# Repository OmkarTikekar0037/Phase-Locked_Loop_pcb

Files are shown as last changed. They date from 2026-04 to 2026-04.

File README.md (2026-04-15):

# Discrete Phase-Locked Loop (PLL) on PCB

This project implements a **fully discrete Phase-Locked Loop (PLL)** using standard logic ICs, analog components, and a voltage-controlled oscillator on a custom PCB. The goal is to bridge theoretical understanding of PLLs with practical hardware realization by designing, building, and analyzing a complete feedback synchronization system.

---

## 🔷 Overview

The PLL is designed to:

* Lock onto an external reference signal (100 Hz – 10 kHz range)
* Perform **frequency multiplication** (×2, ×4, ×8 configurable)
* Demonstrate **lock acquisition (capture)** and **tracking (lock range)** behavior
* Provide observable internal signals for analysis (UP, DOWN, Vctrl, VCO output)

This implementation emphasizes **control system behavior**, **nonlinear dynamics**, and **real-world circuit constraints**.

---

## 🔷 System Architecture

The PLL is composed of the following functional blocks:

1. **Phase Frequency Detector (PFD)**

   * Built using dual D flip-flops and NAND logic
   * Generates UP/DOWN signals based on phase and frequency difference

2. **Charge Pump**

   * Converts digital UP/DOWN pulses into current pulses
   * Controls charging/discharging of the loop filter

3. **Loop Filter (RC Network)**

   * Integrates charge pump output into a smooth control voltage (Vctrl)
   * Defines loop dynamics (bandwidth, damping, stability)

4. **Voltage Controlled Oscillator (VCO)**

   * Implemented using a 555 timer in voltage-controlled mode
   * Output frequency varies with Vctrl

5. **Frequency Divider**

   * Digital counter used to scale down VCO output
   * Enables frequency multiplication in closed loop

---

## 🔷 Key Design Features

* **Second-order PLL design** with tunable damping factor (ζ ≈ 0.7)
* Adjustable loop parameters (R, C, charge pump current)
* Modular block-based design for easy debugging and testing
* Dedicated test points for internal signal observation
* Separation of analog and digital sections for noise reduction

---

## 🔷 Learning Objectives

This project demonstrates:

* Practical implementation of **feedback control systems**

* Relationship between **phase, frequency, and time-domain behavior**

* Design trade-offs between:

  * Stability vs speed
  * Capture range vs noise
  * Loop gain vs oscillation

* Real-world non-idealities:

  * Charge pump mismatch
  * Loop filter noise sensitivity
  * VCO nonlinearity

---

## 🔷 Observations & Experiments

The setup allows direct observation of:

* Lock acquisition process (capture range behavior)
* Stable locked state (minimal phase error)
* Effect of loop filter parameters on system response
* Impact of VCO gain and charge pump current on stability

---

## 🔷 Applications

While implemented as a low-frequency prototype, the same principles apply to:

* Microcontroller clock generation
* RF frequency synthesizers
* Motor synchronization systems
* Communication systems (clock/data recovery)

---

## 🔷 Project Significance

This project serves as a **hardware-level exploration of PLLs**, transforming abstract concepts into measurable electrical behavior. It provides a strong foundation for advanced topics such as:

* High-frequency PLL design
* Digital PLLs (FPGA-based)
* Control system modeling and stability analysis

---

## 🔷 Status

🚧 In development — includes schematic design, PCB layout, and experimental validation.

---

## 🔷 Author

Omkar Tikekar
Electronics & Telecommunication Engineering

---

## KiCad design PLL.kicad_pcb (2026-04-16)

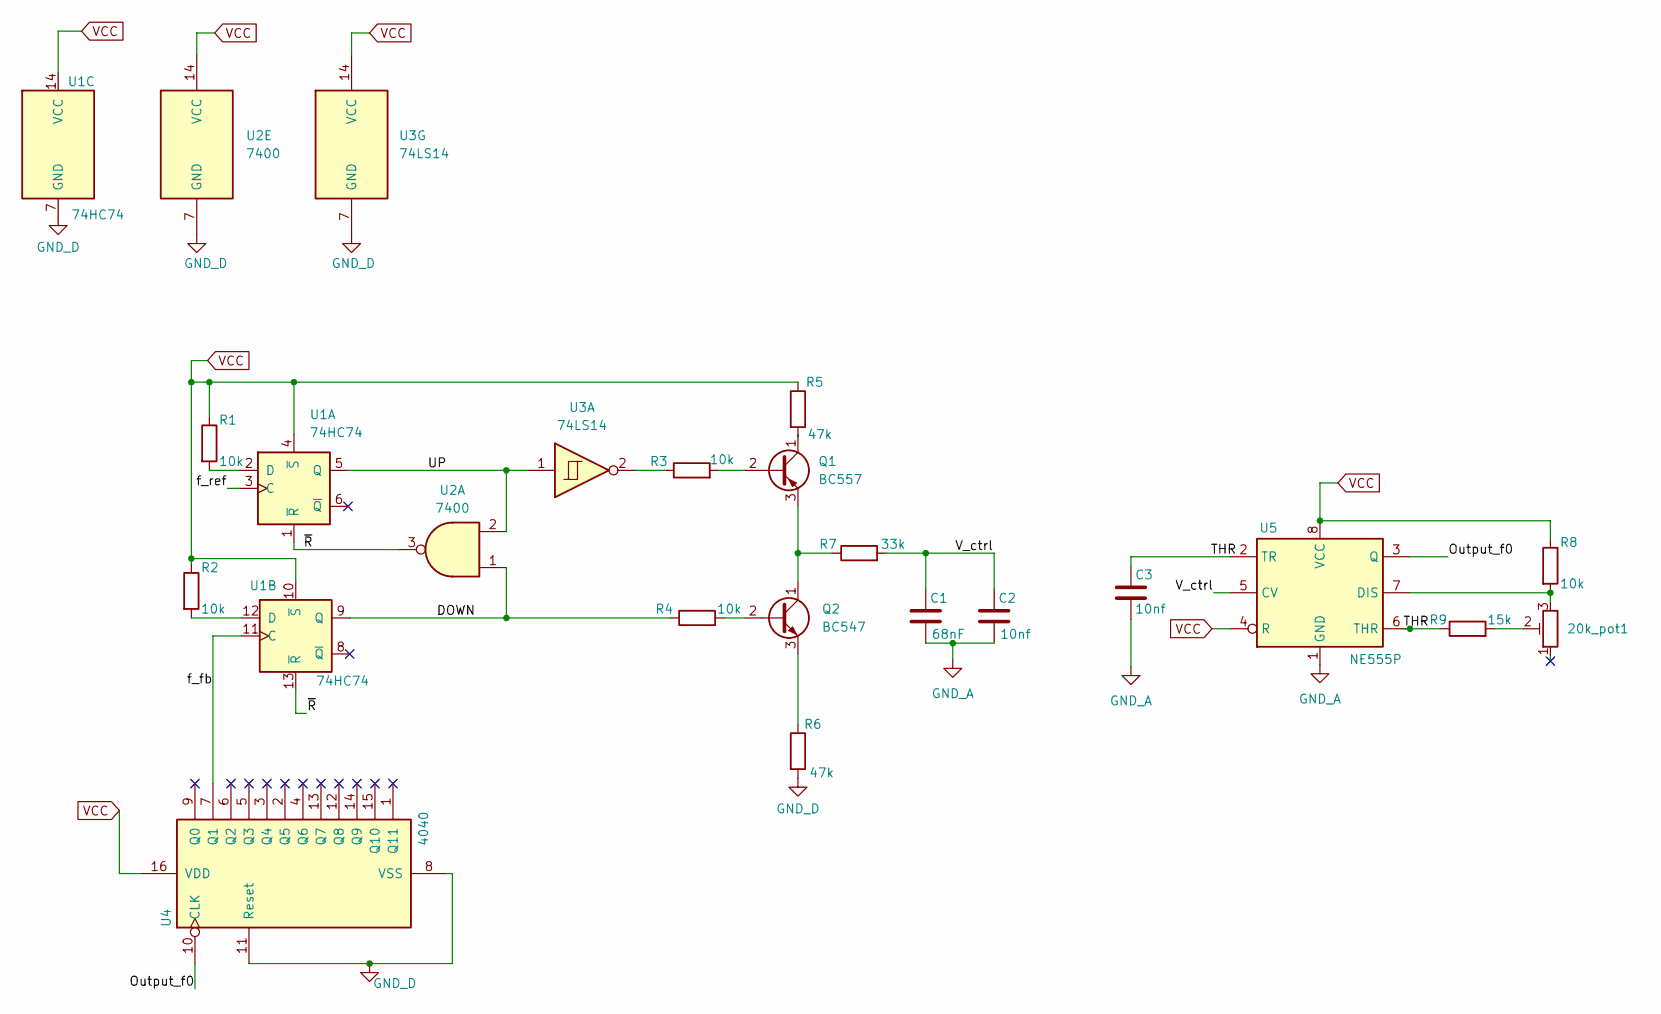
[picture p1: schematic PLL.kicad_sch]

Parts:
20k_pot1: R_Potentiometer_Trim; Potentiometer_Runtron_RM-063_Horizontal
C1: 68nF; C_Disc_D3.0mm_W1.6mm_P2.50mm
C2, C3: 10nf; C_Disc_D3.0mm_W1.6mm_P2.50mm
Q1: BC557; TO-92_Inline
Q2: BC547; TO-92_Inline
R1, R2, R3, R4, R8: 10k; R_Axial_DIN0207_L6.3mm_D2.5mm_P7.62mm_Horizontal
R5, R6: 47k; R_Axial_DIN0207_L6.3mm_D2.5mm_P7.62mm_Horizontal
R7: 33k; R_Axial_DIN0207_L6.3mm_D2.5mm_P7.62mm_Horizontal
R9: 15k; R_Axial_DIN0207_L6.3mm_D2.5mm_P7.62mm_Horizontal
U1: 74HC74; DIP-14_W7.62mm
U2: 7400; DIP-14_W7.62mm
U3: 74LS14
U4: 4040; DIP-16_W7.62mm
U5: NE555P; DIP-8_W7.62mm

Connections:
/DOWN: R4.1, U1.9 (Q), U2.1
/Output_f0: U4.10 (CLK), U5.3 (Q)
/THR: C3.1, R9.1, U5.2 (TR), U5.6 (THR)
/UP: U1.5 (Q), U2.2, U3.1
/V_ctrl: C1.1, C2.1, R7.2, U5.5 (CV)
/f_fb: U1.11 (C), U4.7 (Q1)
/f_ref: U1.3 (C)
/~R: U1.1 (~R), U1.13 (~R), U2.3
GND_A: C1.2, C2.2, C3.2, U5.1 (GND)
GND_D: R6.2, U1.7 (GND), U2.7 (GND), U3.7 (GND), U4.8 (VSS), U4.11 (Reset)
unnamed: 20k_pot1.2, R9.2
unnamed: Q1.2 (B), R3.2
unnamed: Q1.1 (C), R5.2
unnamed: Q1.3 (E), Q2.1 (C), R7.1
unnamed: Q2.2 (B), R4.2
unnamed: Q2.3 (E), R6.1
unnamed: R3.1, U3.2
unnamed: R1.2, U1.2 (D)
unnamed: R2.2, U1.12 (D)
unnamed: 20k_pot1.3, R8.2, U5.7 (DIS)
VCC: R1.1, R2.1, R5.1, R8.1, U1.4 (~S), U1.10 (~S), U1.14 (VCC), U2.14 (VCC), U3.14 (VCC), U4.16 (VDD), U5.4 (R), U5.8 (VCC)

Board: 2 copper layers, 19 parts (0 on the bottom side), 19 nets, no tracks yet.

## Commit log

2026-04-15 initial empty commit
    [PLL.kicad_pcb, PLL.kicad_sch]
2026-04-15 Phase detector completed
    [PLL.kicad_sch]
2026-04-15 BJT push-pull charge pump added
    [PLL.kicad_pcb, PLL.kicad_sch]
2026-04-16 Added Low-Pass Filter and footprints for resistors
    [PLL.kicad_pcb, PLL.kicad_sch]
2026-04-16 555 Timer Voltage controlled oscillator circuitry added
    [PLL.kicad_pcb, PLL.kicad_sch]
2026-04-16 Divide by 4 counter added
    [PLL.kicad_pcb, PLL.kicad_sch]
